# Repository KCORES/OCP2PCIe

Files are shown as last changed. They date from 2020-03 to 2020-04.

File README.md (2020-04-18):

# OCP2PCIe
 OCP 夹层网卡转标准 PCIe 槽转接卡设计  
 OCP Mezzanine card V2.0 to standard PCIe slot adapter design

 KCORES HomeLab 交流群 826702309

# For User
**用户指南**  

如果你想快速制作自己的OCP转接卡，请到[发行页面](https://github.com/KCORES/OCP2PCIe/releases)下载已发布的 Gerber 文件包  
并按[用户指南](doc/UserGuide_zh.md)准备相应的零件

If you want to build a OCP2PCIe card yourself quickly, Please visit [Release](https://github.com/KCORES/OCP2PCIe/releases) to download Gerber zip package  
More detail please bisit [User Guide](doc/UserGuide_zh.md).

# For Developer
**开发者指南**

**[Developer Guide Link](doc/DevGuide_zh.md)**

OCP2PCIe Lib has been updated, now you can create OCP2PCIe design easily.

# 最近动态

1. 正在制作 PCI 挡板的 CAD 图纸，  
不过考虑到小批量钣金加工的成本，可能只有等JS量产了
1. 上传了 OCP2PCIe Lib 现在可以更容易构建你自己的转接卡
1. 更新新版的ReadMe
2. 发布 V2.0Beta

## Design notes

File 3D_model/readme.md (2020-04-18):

## 3D模型说明:mask::mask::mask:  

### version ：0.0.2

-----------------------
|Author|MistyMoon|
|---|---
|E-mail|MistyMoonR@outlook.com

-----------------------
### 

OCP网卡+挡板 是完整STEP图纸

挡板V3.2(合适钣金件) 文件 不需要做任何修改可以直接找JS，建议最好自己检查。

V4 图纸修改说明：移动孔位 可以兼容PCB 0.1bate版本，同时添加散热孔(镂空)

增加半高挡板图纸(镂空)

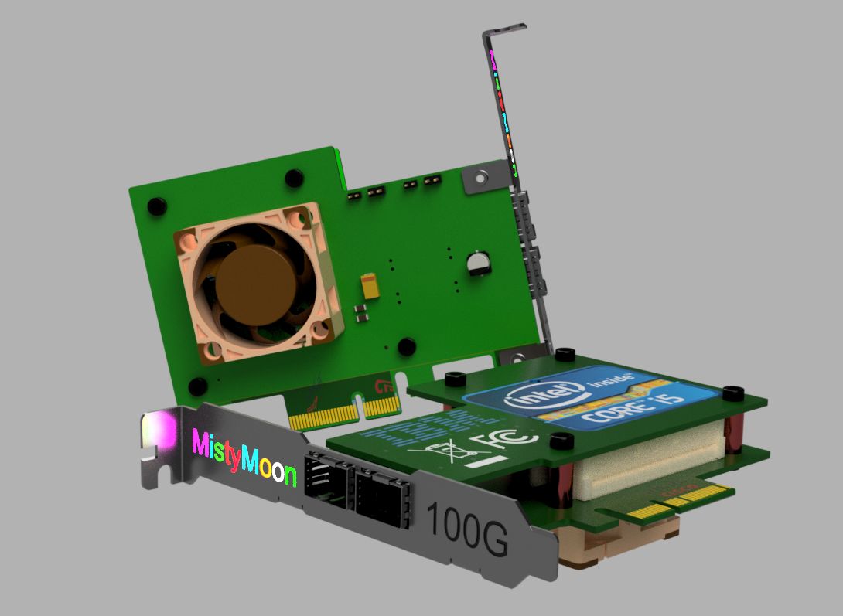
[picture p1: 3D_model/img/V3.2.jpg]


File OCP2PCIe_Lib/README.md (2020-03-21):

# OCP Public Lib

- OCP2PCIe_Lib.pretty  
封装库

- OCP2PCIe_Lib.lib  
符号库

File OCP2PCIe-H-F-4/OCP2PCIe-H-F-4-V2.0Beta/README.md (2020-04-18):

# V2.0 Beta ChangeLog

使用OCP标准库

重新布线

螺丝孔覆铜

单面放置元件

添加切成10x10以内的版本

刷新了版本号

# V1.1 Beta ChangeLog

修正鬼畜布线

覆铜

优化螺丝孔

刷新了版本号

添加切成10x10以内的版本

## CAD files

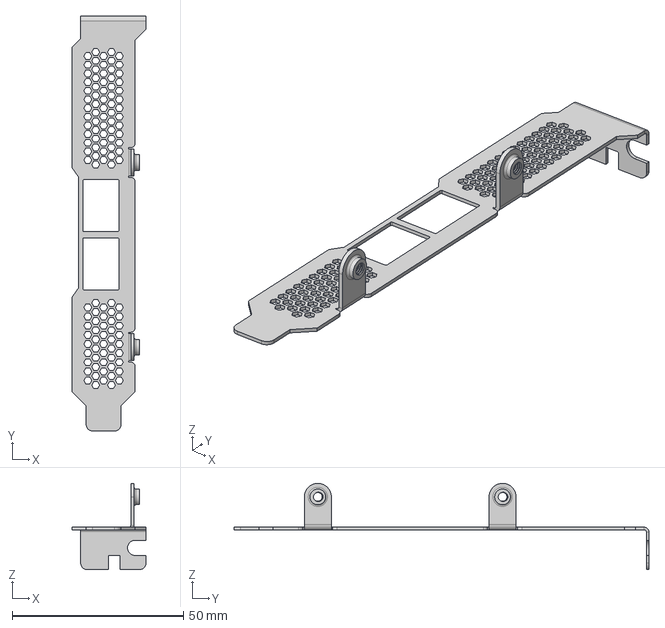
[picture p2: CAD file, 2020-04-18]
3D_model/全高挡板V4(镂空).step
21.6 x 121.1 x 25.2 mm

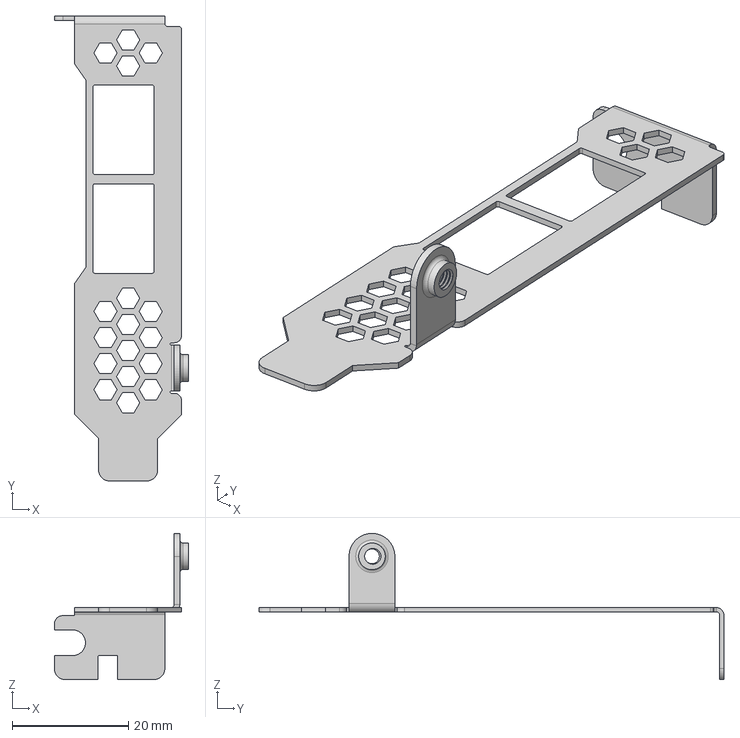
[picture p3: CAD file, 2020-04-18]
3D_model/半高挡板 (镂空).step
23.2 x 80.1 x 25.2 mm

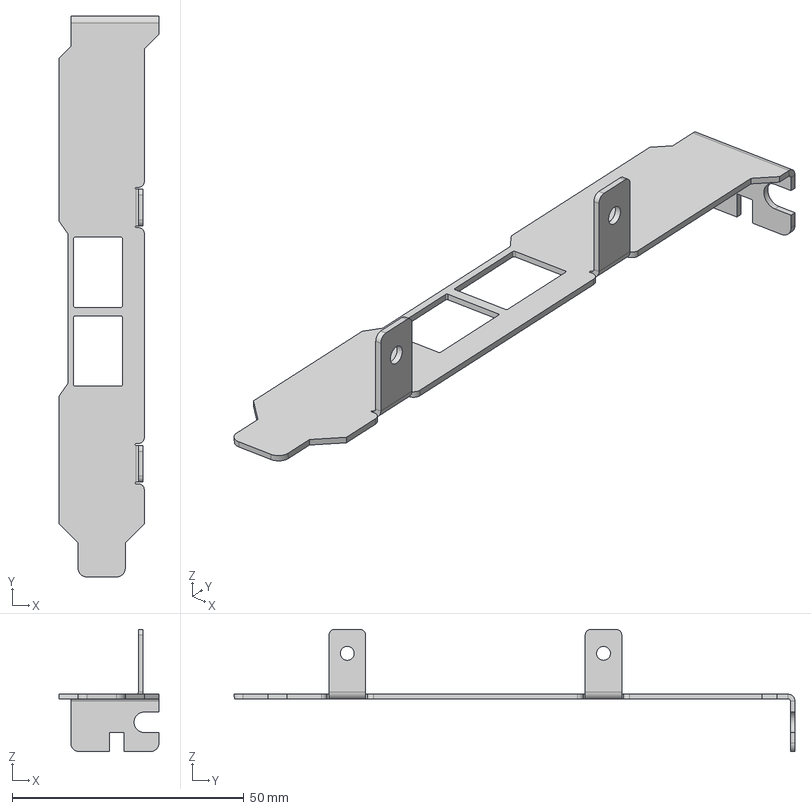
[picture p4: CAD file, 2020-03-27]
3D_model/挡板V3.2(合适钣金件).step
21.6 x 121.1 x 26.4 mm

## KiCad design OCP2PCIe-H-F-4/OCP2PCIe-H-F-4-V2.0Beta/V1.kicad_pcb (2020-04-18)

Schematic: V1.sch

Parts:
C1: C; CP_Elec_6.3x5.4
C2: C; CP_EIA-7343-31_Kemet-D
C3, C4: C; C_1206_3216Metric
J1: PCI Express x4; BUS_PCIexpress_x4
J2: Conn_02x40_Top_Bottom; OCP_Mezz_V2.0
J3, J4: Conn_01x02; PinHeader_1x02_P2.54mm_Vertical
TP1: TestPoint_2Pole; TestPlot
U1: DM02

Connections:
3V3AUX: J1.B10, J2.7, J2.66
+3V3: J1.A9, J1.A10, J1.B8, J2.10, J2.11, J2.12, J2.13, J2.69, J2.70, J2.71, J2.72
+12V: C1.1, J1.A2, J1.A3, J1.B1, J1.B2, J1.B3, J2.61, J2.62, J2.63, J3.1, TP1.1, U1.4
GND: C1.2, C2.2, C3.2, C4.2, J1.A4, J1.A12, J1.A15, J1.A18, J1.A20, J1.A23, J1.A24, J1.A27, J1.A28, J1.A31, J1.B4, J1.B7, J1.B13, J1.B16, J1.B18, J1.B21, J1.B22, J1.B25, J1.B26, J1.B29, J1.B32, J2.5, J2.6, J2.8, J2.9, J2.20, J2.21, J2.24, J2.25, J2.28, J2.29, J2.32, J2.33, J2.36, J2.37, J2.40, J2.41, J2.44, J2.45, J2.48, J2.49, J2.52, J2.53, J2.56, J2.57, J2.60, J2.64, J2.65, J2.67, J2.68, J2.73, J2.79, J2.82, J2.83, J2.86, J2.87, J2.90, J2.91, J2.94, J2.95, J2.98, J2.99, J2.102, J2.103, J2.106, J2.107, J2.110, J2.111, J2.114, J2.115, J2.118, J2.119, J3.2, J4.2, U1.2, U1.3
HSI0_N: J1.A17, J2.31
HSI0_P: J1.A16, J2.30
HSI1_N: J1.A22, J2.35
HSI1_P: J1.A21, J2.34
HSI2_N: J1.A26, J2.39
HSI2_P: J1.A25, J2.38
HSI3_N: J1.A30, J2.43
HSI3_P: J1.A29, J2.42
HSO0_N: J1.B15, J2.89
HSO0_P: J1.B14, J2.88
HSO1_N: J1.B20, J2.93
HSO1_P: J1.B19, J2.92
HSO2_N: J1.B24, J2.97
HSO2_P: J1.B23, J2.96
HSO3_N: J1.B28, J2.101
HSO3_P: J1.B27, J2.100
P5V_AUX: C2.1, C3.1, C4.1, J2.2, J2.3, J2.4, J4.1, TP1.2, U1.1
PERST: J1.A11, J2.17
PRSNT1: J1.A1, J2.1
PRSNT2: J1.B31, J2.120
REFCLK+: J1.A13, J2.84
REFCLK-: J1.A14, J2.85
WAKE: J1.B11, J2.77

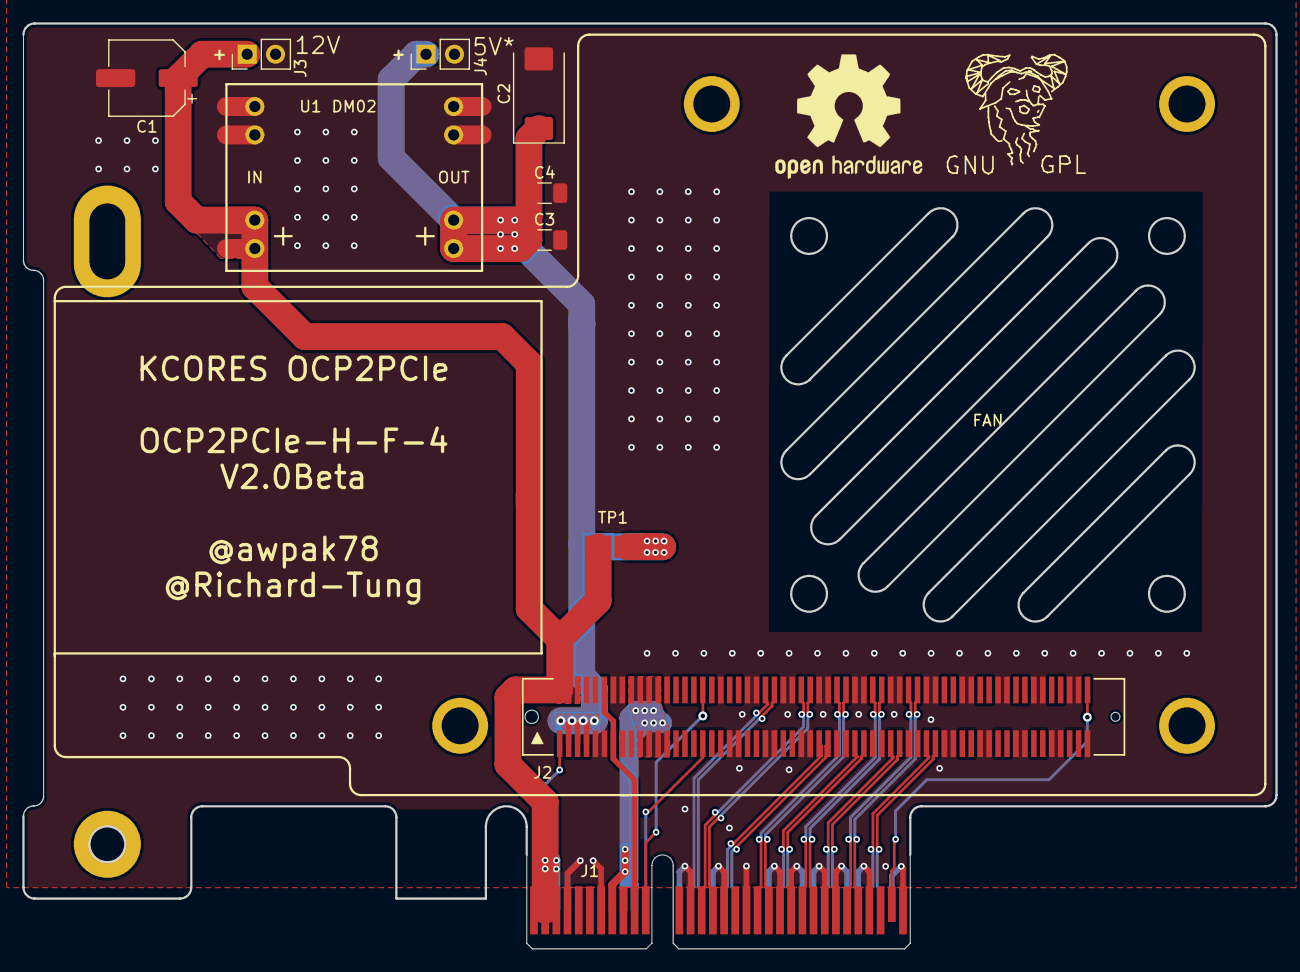
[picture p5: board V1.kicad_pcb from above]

Board: 2 copper layers, 112.1 x 82.8 mm, 11 parts (0 on the bottom side), 27 nets.

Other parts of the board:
FAN: Fan_4010

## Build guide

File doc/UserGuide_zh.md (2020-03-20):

# 快速制作自己的OCP转接卡
by KCORES@awpak78

1. 从[发行页面](https://github.com/KCORES/OCP2PCIe/releases)下载已生成的 Gerber 文件包，这是 PCB 生产通用的工程文件。  
如果你希望为 PCB 添加个性图形或微调尺寸，请下载 KiCAD 工程文件进行修改后自行导出 Gerber。  
**请不要删除作者署名及 Open-Source Hardware 和 GNU GPL 标志**

2. 将 Gerber 文件包上传给 PCB 工厂打样  
 一些 PCB 打样的技术指标
    - 层数：2层
    - 板厚：1.6mm——PCIe卡标准
    - 绝缘漆颜色：随你兴趣——不影响性能
    - 喷镀工艺：喷锡与沉金皆可
        - 喷锡工艺不影响性能，但耐用性较差
        - 沉金价格高昂，多个朋友一起制作才能降低成本
    - 铜厚：1盎司

3. 零件准备
    - OCP 插座推荐使用 FCI 61082-12**2**400 —— 加粗的 **2** 是插座的高度代号  
    或 FCI 61082-12**3**400 这款插座更高，可能会占用下一条 PCI 插槽  
    还有一种方案是 61082-12**1**400 + PCB 垫高板，由于这款插座有廉价的国产替代品，因此备受淘宝JS喜爱
    - M3铜柱 母头对母头，根据不用的插座高度选择
        - FCI 61082-122400 —— 12mm
        - FCI 61082-123400 —— 16mm
        - 61082-121400 + PCB 垫高 —— 未知
    - M3螺丝 8粒

4. 焊接与安装
    - 焊接是最难的一步，有热风枪事半功倍，调温电烙铁也可以接受
    - **请务必单独购买焊锡丝，所有电烙铁附赠的焊锡都是垃圾**
    - 除了建议大家多看点拖焊教程，我也没有办法提供其它的建议，毕竟我就是菜鸡

5. **MCX341用户一定要焊接背面的TP1焊点，为5V引脚通入12V供电**

5. **⚠在上机之前，必须测试引脚之间是否短路**

5. 享受万兆内网吧

# MCX341A改双网口教程

[家用万兆网络指南 6 - 比网线还便宜的双口万兆网卡. 如何给Mellanox网卡刷固件或备份固件](https://zhuanlan.zhihu.com/p/114822136)  
by Karminski-牙医

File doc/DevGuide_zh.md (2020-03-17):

# OCP2PCIe
 OCP 夹层网卡转标准 PCIe 槽转接卡设计  
 OCP Mezzanine card V2.0 to standard PCIe slot adapter design
 
 请使用最新版 KiCAD 编辑  
 Please use the latest KiCAD version
 
 KCORES HomeLab 交流群 826702309

# Catalog
**目录**
- **Directory Description**  
 **文件说明**   
 
  - Name Rule  
   项目命名规则  
 
- **Manufacturing instructions**  
**制造说明**

- **Some Problem**  
**疑难问题**

  - About PCIe Lanes Sequence  
   关于 PCIe 通道顺序问题
   
  - ⚠About 5V Power⚠  
   关于5V供电

# Directory Description
**文件说明**  

`\OCP2PCIe_Lib`  
OCP2PCIe 公共 KiCAD 库  
OCP2PCIe public KiCAD lib

`\OCP2PCIe-*-*-*`  
项目分类，命名规则见下一节  
Project classification, see the next section

## Name Rule
 **项目命名规则**  
 
 `OCP2PCIe-H-F-4-V0.1`  @
 
 - OCP2PCIe 项目名称 / Project Name  
 
 - H: 全高 PCI 卡 / Standard Height PCI Card  
 L: 半高 PCI 卡 / Low-Profile PCI Card
 
 - F: PCIe 通道顺序连接 / PCIe lane sequential connection  
 R: PCIe 通道逆序连接 / PCIe lane reverse connection  
 详细描述见最后一节 / See the last paragraph for a detailed explanation
 
 - 1/2/4/8/16: PCIe 通道数 / PCIe Lanes  
 
 - V0.1: 版本号 / Version
 
# Manufacturing instructions
**制造说明**

undone

# Some Problem 
**疑难问题**

## About PCIe Lanes Sequence
**关于 PCIe 通道顺序问题**

OCP卡有两种不同的连接方式，目前已知这两种方式都可以工作，但具体的性能和稳定性影响未知  
OCP Mezz has two different connection methods. Currently it is known that both methods can work, but the specific performance and stability impact is unknown.

- 顺序连接 / Sequential connection  
OCP插槽通道与PCIe通道按顺序相连，如0-0、1-1、2-2、3-3  
The OCP slot lanes are sequentially connected to the PCIe lanes, etc: 0-0, 1-1, 2-2, 3-3  

- 逆序连接 / Reverse link  
OCP插槽通道与PCIe通道按逆序相连，如7-0、6-1、5-2、4-3  
The OCP slot lanes are sequentially connected to the PCIe lanes, etc: 7-0, 6-1, 5-2, 4-3

## About 5V Power
**关于5V供电**

OCP规范需要5V辅助供电，目前已知情况如下：  
 The OCP specification requires a 5V auxiliary power supply. The current known situation is as follows:  

- 不需要5V  
 Don't need 5V
    - intel X540

- 需要5V，但5V电路元器件与12V一致，可以直接与12V连接  
 5V is required, but the 5V circuit components are consistent with 12V and can be directly connected to 12V
    - Mellanox MCX341A  
    - Mellanox MCX342A

- 必须提供稳定的5V供电  
 Must provide stable 5V power
    - 未知 / Uknown

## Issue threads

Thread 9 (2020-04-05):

C2电容错误

Xanadu-Zen, 2020-04-05:
原理图中C2电容所设置的封装为```Capacitor_Tantalum_SMD:CP_EIA-7343-31_Kemet-D```的钽电容，但原理图中使用了无极性电容的符号，按照原理图导入PCB编辑器后发现电容丝印反向。
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

虽然不是什么大问题，感觉还是改一下的好。

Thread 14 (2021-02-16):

高速信号阻抗匹配

nightseas, 2021-02-16:
### Issue

双层PCB，8G/T的PCIe信号没有阻抗匹配，信号质量无法保证
 - 没有参考地平面
 - 过孔没有伴地孔（return via）

### Suggestion

改为4层板（一些厂家如JLC的4层板不算贵），按照厂家的叠层计算阻抗（线宽、线间距）。
PCIe过孔处增加伴地孔。

alphaarea, 2021-03-02:
开源设计主要考虑易DIY性，**做4层设计只会更方便JS白嫖**，对爱好者无益
在可用性差异不大的前提下，以后的开源设计也会坚持2层，除非PCIe Gen4洋垃圾靠岸

已经在SI9000中按共面铺地模型进行阻抗计算，至于实际能有多少就随缘吧……
就现在这样转接卡都已经比万兆网卡本身贵了……

Closed 2021-03-05.

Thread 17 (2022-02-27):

你好ocp b这个有没有什么方案 谢谢

skullcrossbones, 2022-02-27:

alphaarea, 2022-02-28:
请详细描述一下你的问题

maz-1, 2022-04-25:
>

他大概说的80 pin Connector B吧，就是增加了80pin接口支持x16的带宽

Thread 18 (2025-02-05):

Ocp 3 riser in the future?

missmah, 2025-02-05:
Seems like 2x MCIO x8 to OCP 3.0 x16 riser cable could be made

Civil, 2025-05-01:
I've recently found these adapters for sale on the internet:
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

They are branded as KCores, however, I haven't seen any schematics or even documentation on those around (I'm curious about what those dip switches do, what the specs of those are, etc). Is there any more information available about those?

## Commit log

2020-03-18 Update OSHW and GNU Logo
    [V1.kicad_pcb]
2020-03-19 Update V1.0 Beta
    [V1.kicad_pcb, V1.sch]
2020-03-26 v1.1 update
    [V1.kicad_pcb, V1.sch]
2020-03-27 v1.1: add 10x10 cut version
    [v1-cut10x10.kicad_pcb]
2020-03-27 Add 3D_modle
    包含图纸，说明文档
    [挡板V3.2(合适钣金件).step]
2020-04-18 v2.0 beta
    [V1-cut10x10.kicad_pcb, V1.kicad_pcb, V1.sch]
2020-04-18 add new model
    [全高挡板V4(镂空).step, 半高挡板 (镂空).step]
